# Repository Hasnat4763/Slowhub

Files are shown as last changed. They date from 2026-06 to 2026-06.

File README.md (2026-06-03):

# Slowhub

A USB 2.0 hub based on the SL2.1A

# Why did I make it

I had designed another USB 2.0 hub with the same chip before, but I did not have a lot of experience Back then so when I received the PCB, the hub was not fully working, the audio Input/Output part was working great but It could not handle connecting USB peripherals like Pendrives and Keyboard/Mouse. So I decided to design another USB Hub with it to fix the past mistakes. 

# Gallery

## PCB

# Schematic

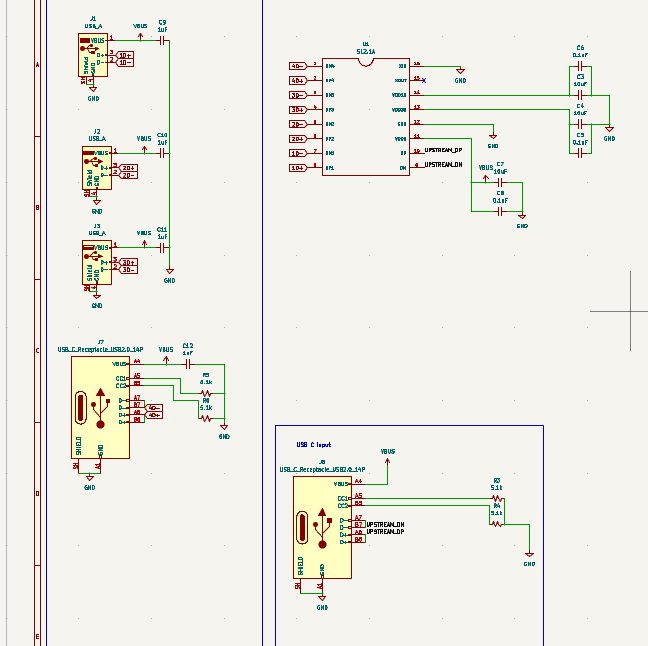
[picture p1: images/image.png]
Schematic


# PCB

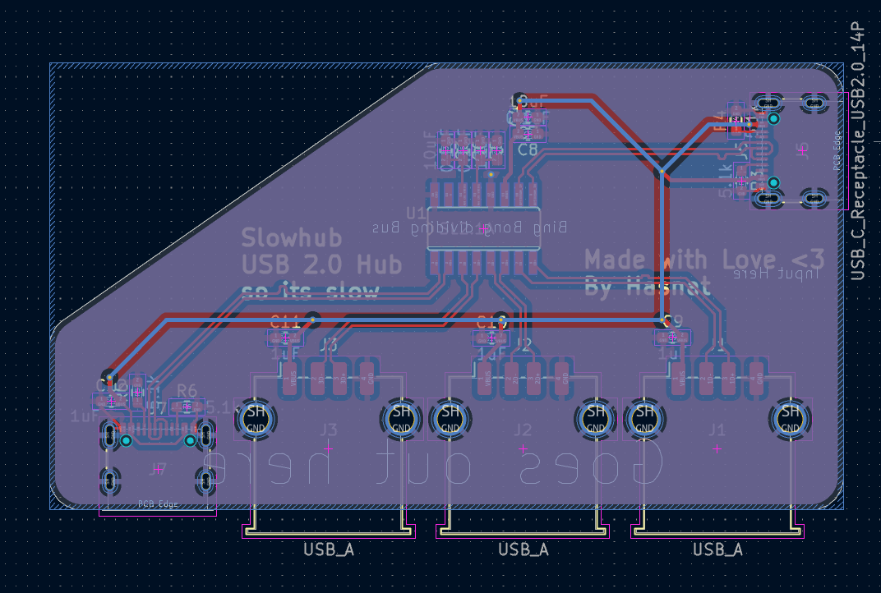
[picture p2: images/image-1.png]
PCB


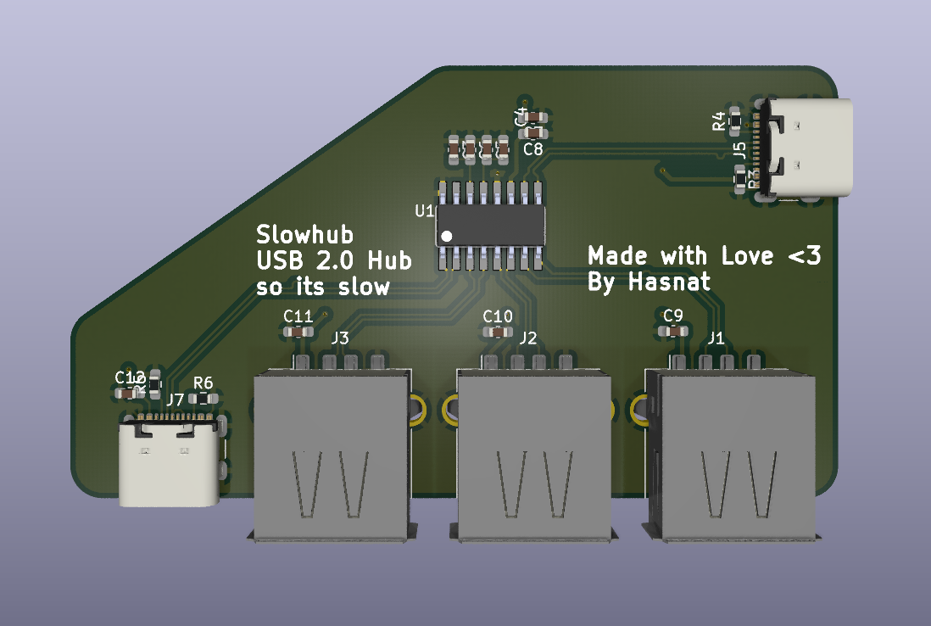
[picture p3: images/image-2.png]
PCB 3D render


# Case

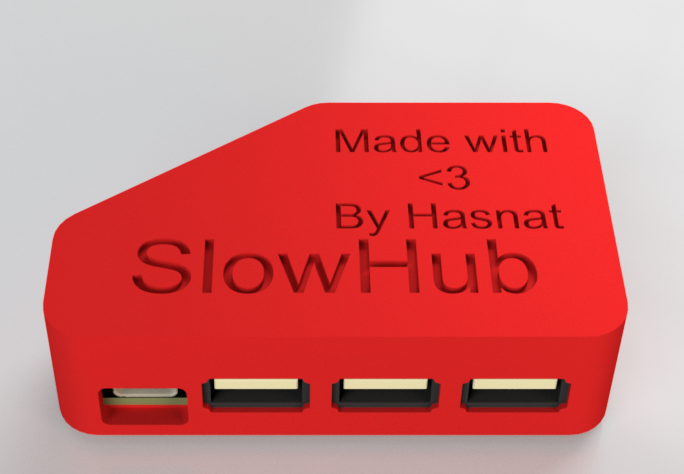
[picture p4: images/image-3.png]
Fully Assembled


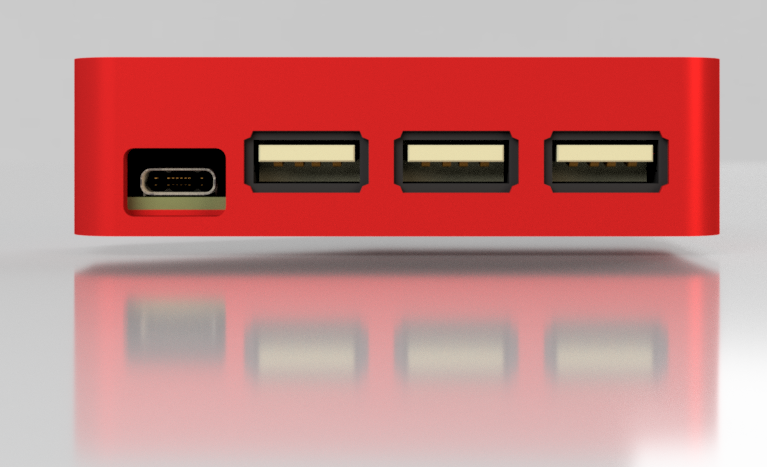
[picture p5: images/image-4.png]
ports from side


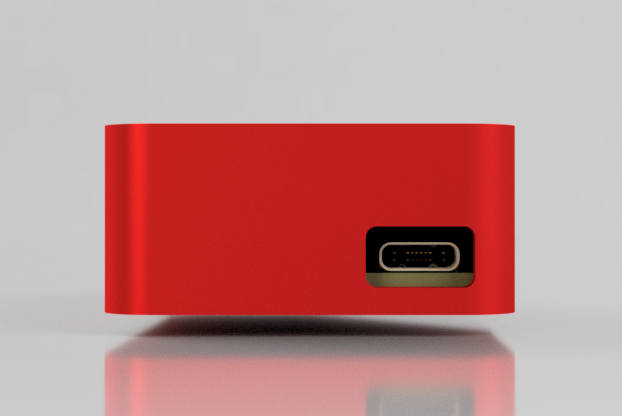
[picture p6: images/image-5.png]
Input Port


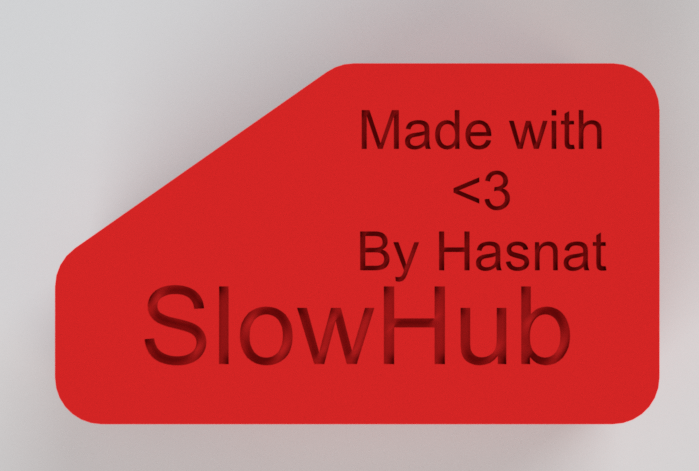
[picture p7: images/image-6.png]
Case from top


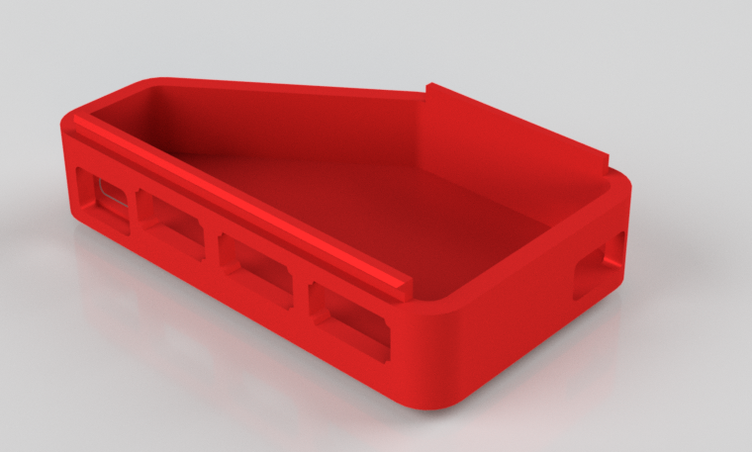
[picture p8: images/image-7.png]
case bottom


# BOM

| Part name | Quantity | Price | Product Link |
|---|---|---|---|
| SL2.A USB HUB IC | 5 | $1.40 | [Link](https://www.aliexpress.com/item/1005005552905296.html) |
| USB A Female Port | 10 | $5.68 | [Link](https://www.aliexpress.com/item/1005010243685669.html) |
| USB C Female Port (TYPE-C-02) | 10 | $2.06 | [Link](https://www.aliexpress.com/item/1005005371954812.html) |
| Capacitor Kit (0.1uF, 1uf, 10uF) | 1 | $3.67 | [Link](https://www.aliexpress.com/item/1005007293819361.html) |
| 5.1k Resistor 0603 | 100 | $1.73 | [Link](https://www.aliexpress.com/item/1005008152622017.html) |
| PCB | 5 | $0.18 | JLCPCB |
| 3D printed Case Parts | 2 | Printing Legion | Printing Legion HC |

# Build instruction

You will have to use SMD soldering for soldering 90% of the parts. you may need a stencil if you want to use a hot plate, but a soldering iron can be used too.

# Zine

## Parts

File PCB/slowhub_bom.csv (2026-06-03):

Designator | Footprint | Quantity | Value | LCSC Part #
C10, C11, C12, C9 | 0603 | 4 | 1uF
C3, C4, C7 | 0603 | 3 | 10uF
C5, C6, C8 | 0603 | 3 | 0.1uF
J1, J2, J3 | USB_A_TE_292303-7_Horizontal | 3 | USB_A
J5, J7 | USB_C_Receptacle_GCT_USB4105-xx-A_16P_TopMnt_Horizontal | 2 | USB_C_Receptacle_USB2.0_16P
R3, R4, R5, R6 | 0603 | 4 | 5.1k
U1 | SO16 | 1 | SL2.1A

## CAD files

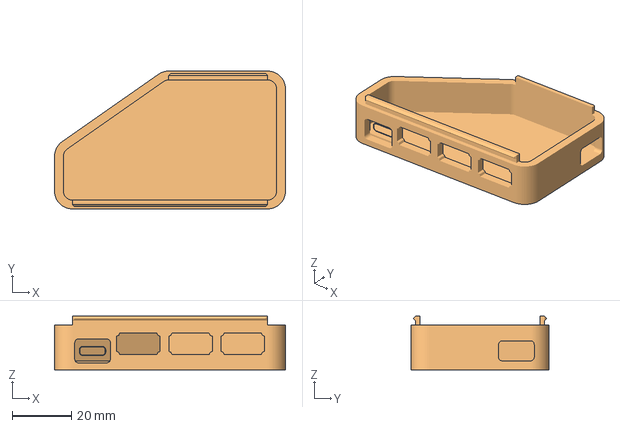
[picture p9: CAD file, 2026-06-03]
CAD/Slowhub bottom.3mf
77.7 x 46.4 x 18.0 mm

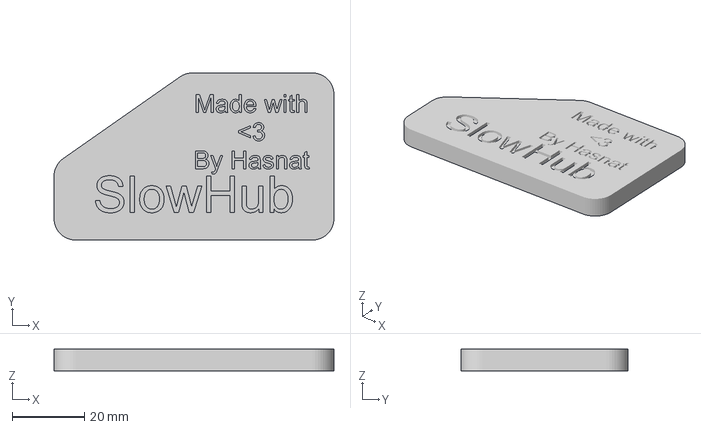
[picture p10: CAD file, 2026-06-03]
CAD/Slowhub Top.3mf
77.7 x 46.4 x 6.00 mm

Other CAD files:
CAD/slowhub assembled.f3z

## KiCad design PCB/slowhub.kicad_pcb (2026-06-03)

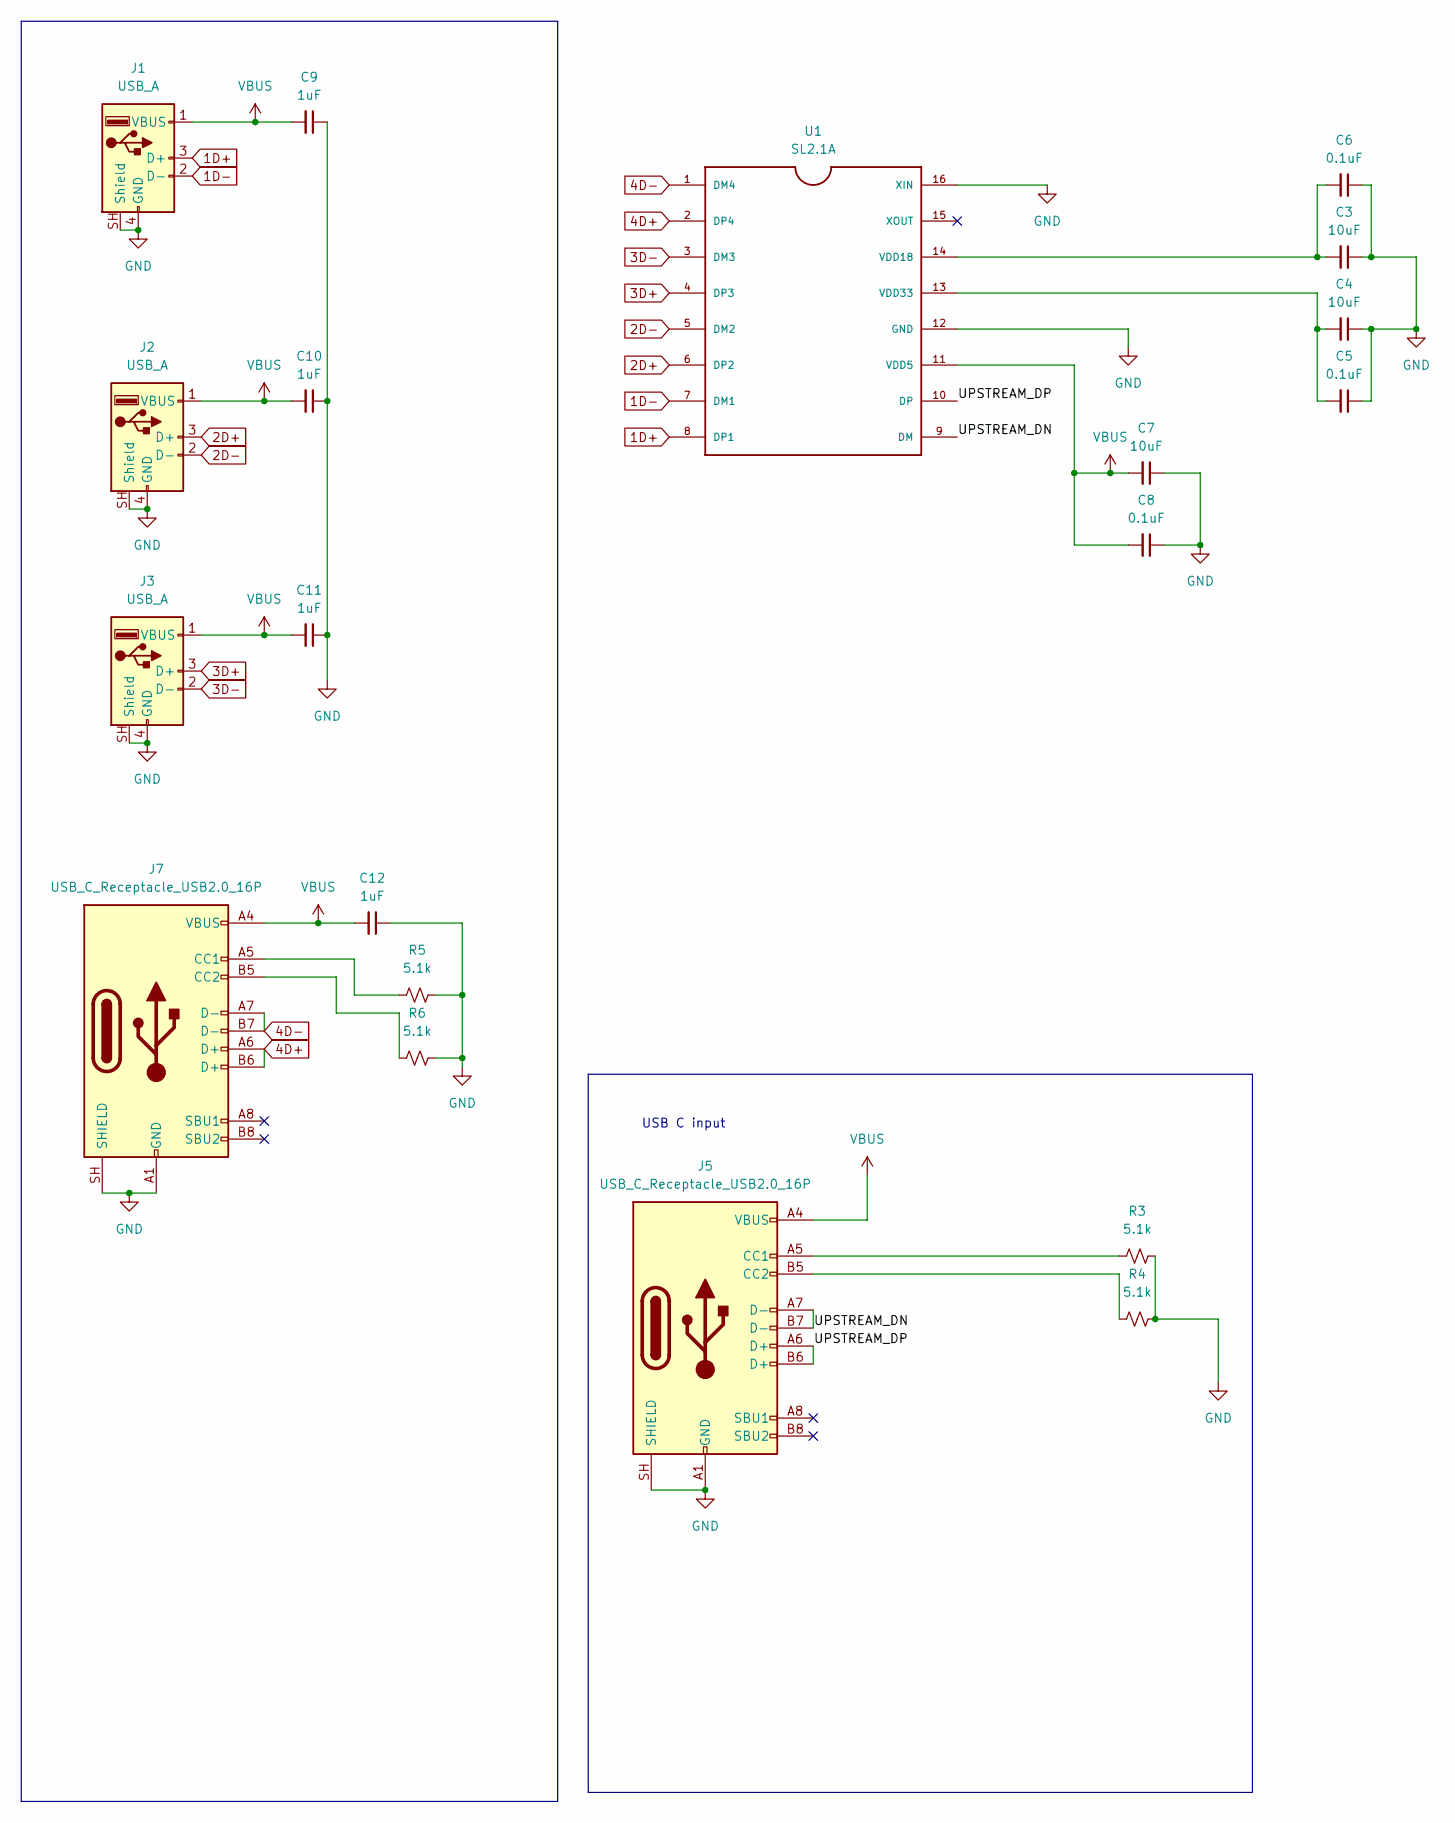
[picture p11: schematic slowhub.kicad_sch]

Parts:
C3, C4, C7: 10uF; C_0603_1608Metric_Pad1.08x0.95mm_HandSolder
C5, C6, C8: 0.1uF; C_0603_1608Metric_Pad1.08x0.95mm_HandSolder
C9, C10, C11, C12: 1uF; C_0603_1608Metric_Pad1.08x0.95mm_HandSolder
J1, J2, J3: USB_A; USB_A_TE_292303-7_Horizontal
J5, J7: USB_C_Receptacle_USB2.0_16P; USB_C_Receptacle_GCT_USB4105-xx-A_16P_TopMnt_Horizontal
R3, R4, R5, R6: 5.1k; R_0603_1608Metric_Pad0.98x0.95mm_HandSolder
U1: SL2.1A; SO16

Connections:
1D+: J1.3 (D+), U1.8 (DP1)
1D-: J1.2 (D-), U1.7 (DM1)
2D+: J2.3 (D+), U1.6 (DP2)
2D-: J2.2 (D-), U1.5 (DM2)
3D+: J3.3 (D+), U1.4 (DP3)
3D-: J3.2 (D-), U1.3 (DM3)
4D+: J7.A6 (D+), J7.B6 (D+), U1.2 (DP4)
4D-: J7.A7 (D-), J7.B7 (D-), U1.1 (DM4)
/UPSTREAM_DN: J5.A7 (D-), J5.B7 (D-), U1.9 (DM)
/UPSTREAM_DP: J5.A6 (D+), J5.B6 (D+), U1.10 (DP)
GND: C3.1, C4.1, C5.1, C6.1, C7.1, C8.1, C9.1, C10.1, C11.1, C12.1, J1.4 (GND), J1.SH (Shield), J2.4 (GND), J2.SH (Shield), J3.4 (GND), J3.SH (Shield), J5.A1 (GND), J5.A12 (GND), J5.B1 (GND), J5.B12 (GND), J5.SH (SHIELD), J7.A1 (GND), J7.A12 (GND), J7.B1 (GND), J7.B12 (GND), J7.SH (SHIELD), R3.2, R4.2, R5.2, R6.2, U1.12 (GND), U1.16 (XIN)
unnamed: J5.A5 (CC1), R3.1
unnamed: J5.B5 (CC2), R4.1
unnamed: J7.A5 (CC1), R5.1
unnamed: J7.B5 (CC2), R6.1
unnamed: C3.2, C6.2, U1.14 (VDD18)
unnamed: C4.2, C5.2, U1.13 (VDD33)
VBUS: C7.2, C8.2, C9.2, C10.2, C11.2, C12.2, J1.1 (VBUS), J2.1 (VBUS), J3.1 (VBUS), J5.A4 (VBUS), J5.A9 (VBUS), J5.B4 (VBUS), J5.B9 (VBUS), J7.A4 (VBUS), J7.A9 (VBUS), J7.B4 (VBUS), J7.B9 (VBUS), U1.11 (VDD5)

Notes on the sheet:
USB C input

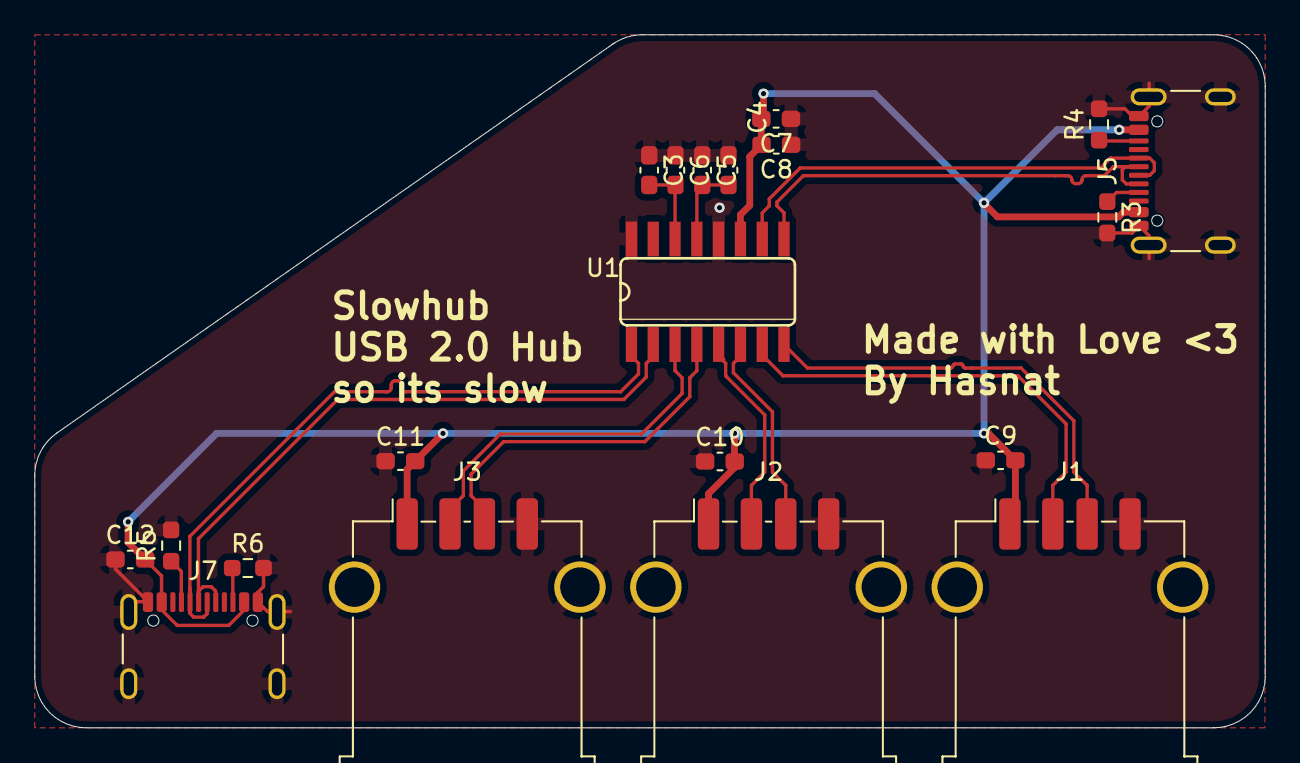
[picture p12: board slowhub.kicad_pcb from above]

Board: 2 copper layers, 71.7 x 40.4 mm, 20 parts (0 on the bottom side), 18 nets.

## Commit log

2026-06-03 Add stuff
    [Slowhub Top.3mf, Slowhub bottom.3mf, slowhub assembled.f3z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]
2026-06-03 BOM Markdown fixing
